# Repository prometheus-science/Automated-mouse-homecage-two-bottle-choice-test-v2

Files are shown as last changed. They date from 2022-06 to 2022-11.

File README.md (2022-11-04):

# Automated-mouse-homecage-two-bottle-choice-test-v2
  
## a fork of the Kravitz lab device hosted on hackaday https://hackaday.io/project/160388  
  
|components:  |links|Digikey|
|--|--|--|
|1 	× 	3D printed housing and cover See files area for STLs  |||
|1 	× 	Adafruit M0 Feather Adalogger| https://www.adafruit.com/product/2796  |https://www.digikey.co.uk/en/products/detail/adafruit-industries-llc/2796/5804105|
|2 	× 	Hydropac valves| https://labproductsinc.com/product/hydropac-alternative-watering-system/  ||
|2 	× 	15mL conical tube | https://www.amazon.com/Plastic-Graduated-Centrifuge-Measuring-Conical/dp/B07BF6GCXP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  ||
|1 	× 	3 cell battery| https://www.adafruit.com/product/353  ||
|1 	× 	Short female headers for Feather |https://www.adafruit.com/product/2940  |https://www.digikey.co.uk/en/products/detail/sullins-connector-solutions/PPPC161LFBN-RC/810188|
|1 	× 	Adafruit Feather OLED wing| https://www.adafruit.com/product/2900  |https://www.digikey.co.uk/en/products/detail/adafruit-industries-llc/2900/5810890|
|2 	× 	JST 11" 3 pin assemblies| https://vetco.net/products/jst-ph-connector-male-female-pair-pre-wired-3-pin  |https://www.digikey.co.uk/en/products/detail/jst-sales-america-inc/ASPHSPH24K305/6009459 and https://www.digikey.co.uk/en/products/detail/jst-sales-america-inc/PHR-3/527357|
|2 	× 	JST 3 pin right angle connector |https://www.digikey.com/products/en?keywords=S3B-PH-K-S(LF)(SN)  |https://www.digikey.co.uk/en/products/detail/jst-sales-america-inc/S3B-PH-K-S-LF-SN/926627|
|2 	× 	SparkFun Photo Interrupter Breakout Board - GP1A57HRJ00F| https://www.sparkfun.com/products/9322  |https://www.digikey.co.uk/en/products/detail/sparkfun-electronics/BOB-09322/6006049|
|2 	× 	Resistor 1K Ohm 1/4th Watt| https://www.sparkfun.com/products/13760  |https://www.digikey.co.uk/en/products/detail/stackpole-electronics-inc/CF14JT1K00/1741314|
|2 	× 	Photo Interrupter - GP1A57HRJ00F| https://www.sparkfun.com/products/9299  |https://www.digikey.co.uk/en/products/detail/sharp-socle-technology/GP1A57HRJ00F/718287|
|2 	× 	(optional) BNC output cables | http://www.l-com.com/coaxial-test-cable-bnc-female-6-leads-with-tinned-end  |https://www.digikey.co.uk/en/products/detail/mueller-electric-co/BU-P4969/4073809|
|1 	× 	microSD card 8g class4  ||https://www.digikey.co.uk/en/products/detail/parallax-inc/32328/8638942|

an easier to print frame: 
https://www.tinkercad.com/things/bckWmv0TgYV

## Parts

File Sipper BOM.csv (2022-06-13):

Qty | Part | Link | Price | Total
1 | Adafruit Feather M0 Adalogger | https://www.adafruit.com/product/2796 | $19.95 | $19.95
1 | Lithium Ion Battery Pack - 3.7V 6600mAh | https://www.adafruit.com/product/353 | $29.50 | $29.50
1 | Adafruit FeatherWing OLED - 128x32 OLED | https://www.adafruit.com/product/2900 | $14.95 | $14.95
1 | Short Headers Kit for Feather - 12-pin + 16-pin Female Headers | https://www.adafruit.com/product/2940 | $1.50 | $1.50
2 | 1k resistor | any brand or supplier will do | $0.20 | $0.40
2 | Photo Interrupter - GP1A57HRJ00F | https://www.sparkfun.com/products/9299 | $2.50 | $5.00
2 | SparkFun Photo Interrupter Breakout Board - GP1A57HRJ00F | https://www.sparkfun.com/products/9322 | $1.50 | $3.00
1 | MicroSD card | https://www.amazon.com/Kingston-microSDHC-Class-Memory-SDC4/dp/B00200K1TS/ | $6.00 | $6.00
2 | JST cable | https://www.sparkfun.com/products/9915 | $1.50 | $3.00
2 | Plastic valves | https://labproductsinc.com/product/hydropac-alternative-watering-system/ | $0.50 | $1.00
2 | 10mL syringes | https://www.amazon.com/dp/B01JJYDFHM | $0.50 | $1.00
Total |  |  |  | $85.30

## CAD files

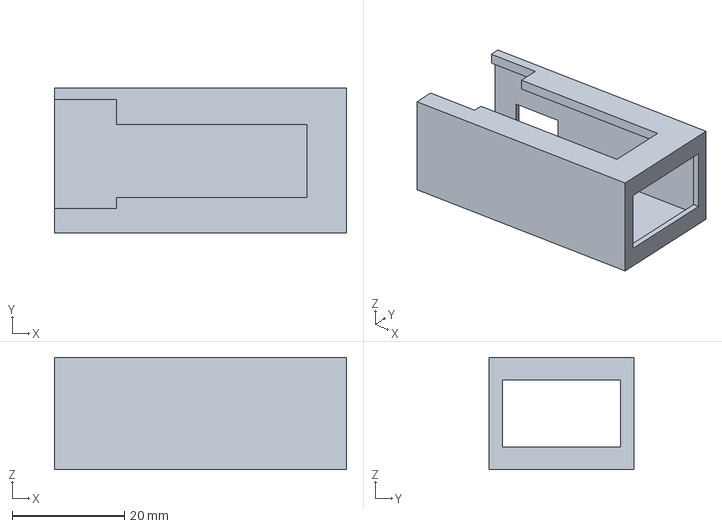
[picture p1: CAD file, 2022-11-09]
3D_models/derivative/freecad_remodel/motor_fit_test.amf
52.0 x 25.9 x 20.0 mm

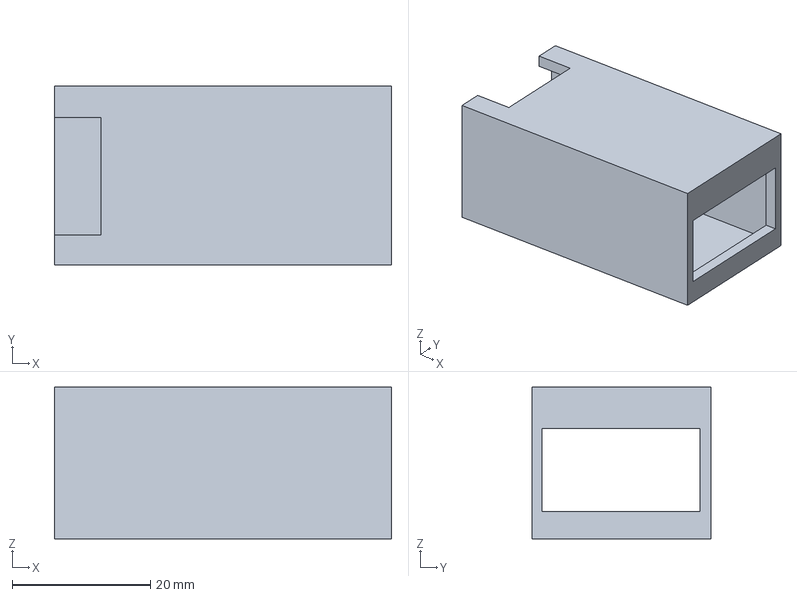
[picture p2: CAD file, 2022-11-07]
3D_models/derivative/test_electronics_fit.amf
48.8 x 25.9 x 22.0 mm

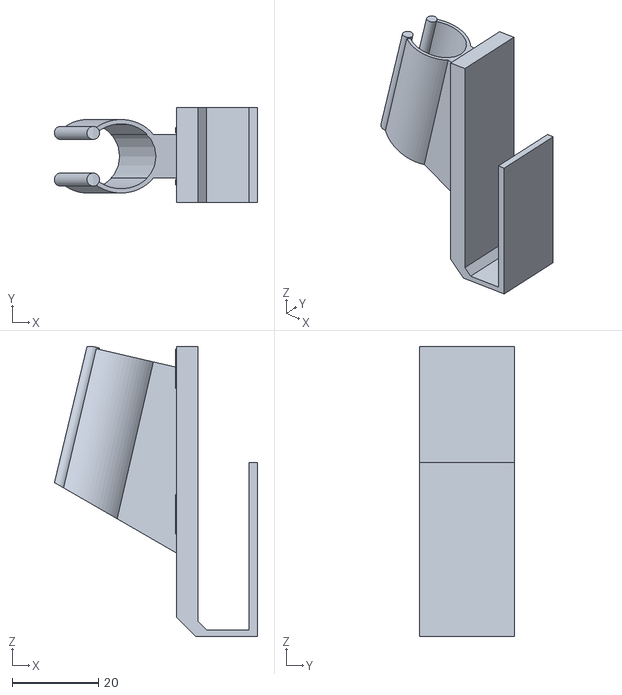
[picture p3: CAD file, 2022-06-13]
3D_models/Mini sipper tube holder.stl
47.0 x 22.0 x 67.1

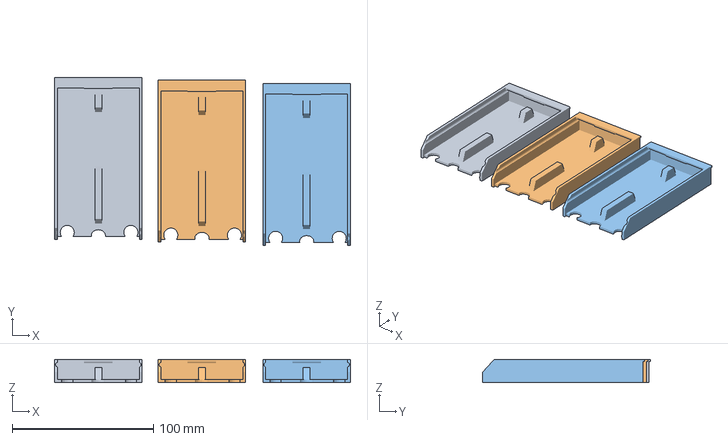
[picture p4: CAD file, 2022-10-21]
3D_models/derivative/electronics_holder_creality.3mf
209.3 x 118.7 x 16.5 mm
sipper_cover.stl x 3

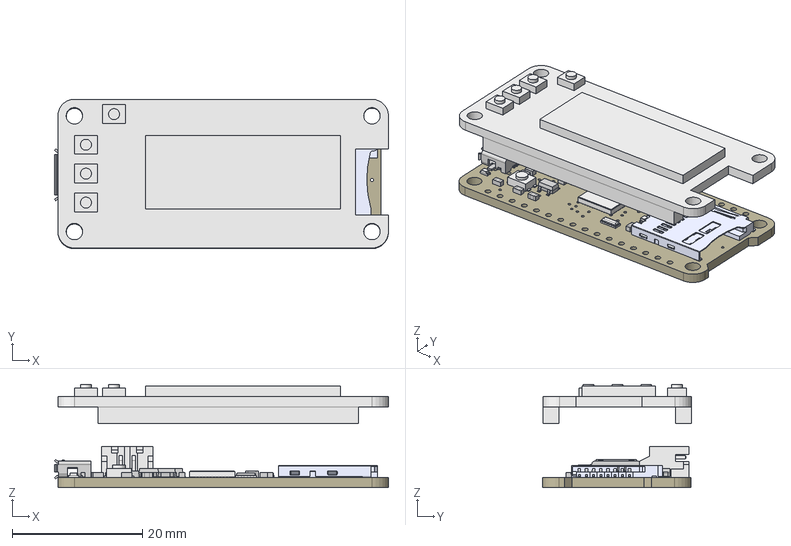
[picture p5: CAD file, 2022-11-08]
3D_models/derivative/freecad_remodel/remodel_freecad.FCStd
51.3 x 23.0 x 15.9 mm
Board
0805-NO
0805-NO001
0805-NO002
0805-NO003
0603-NO
0603-NO001
0603-NO002
0603-NO003
0603-NO004
0603-NO005
0603-NO006
0603-NO007
0603-NO008
0603-NO009
CHIPLED_0805_NOOUTLINE
CHIPLED_0805_NOOUTLINE001
CHIPLED_0805_NOOUTLINE002
TQFN44_7MM
KMR2
RESONATOR-SMD
4UCONN_20329_V2
SOT23-5
SOT23-006
SOD-123
JSTPH2
MICROSD
_0603MP
Feather OLED Wing v11

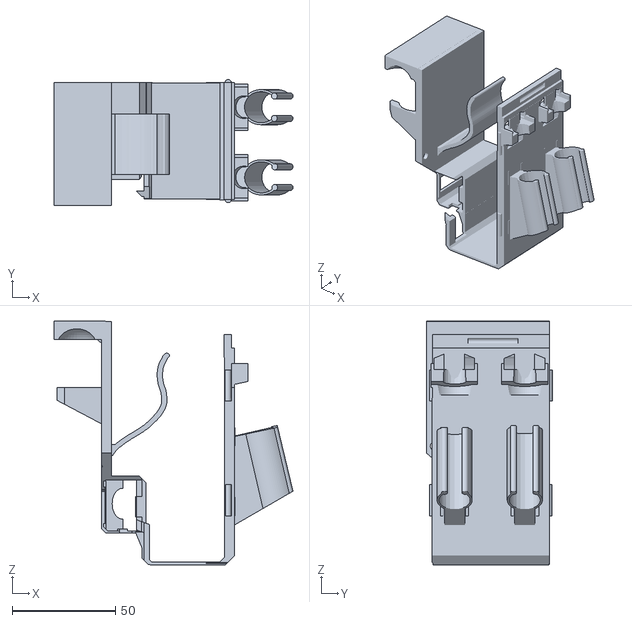
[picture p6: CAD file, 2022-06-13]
3D_models/Sipper base.stl
115.5 x 60.9 x 117.8

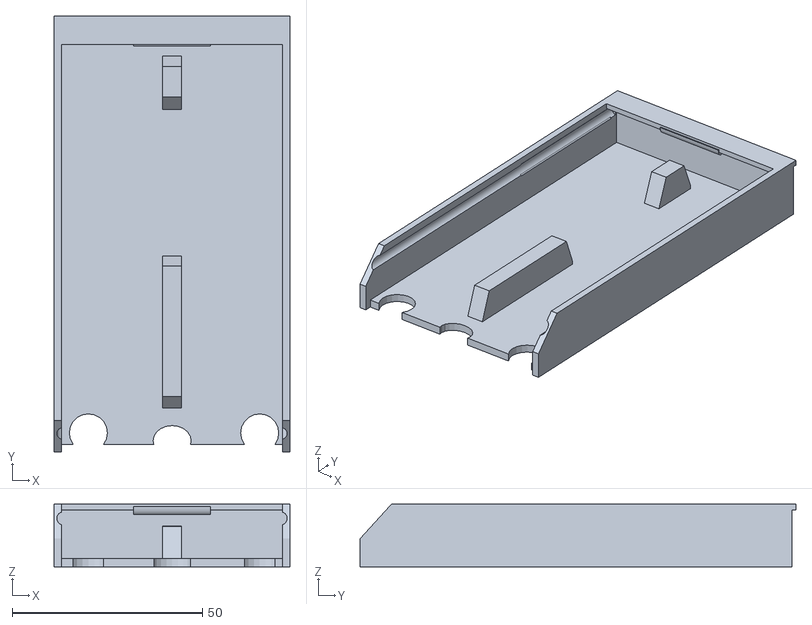
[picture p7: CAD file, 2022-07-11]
3D_models/derivative/sipper_cover.stl
62.0 x 114.5 x 16.5

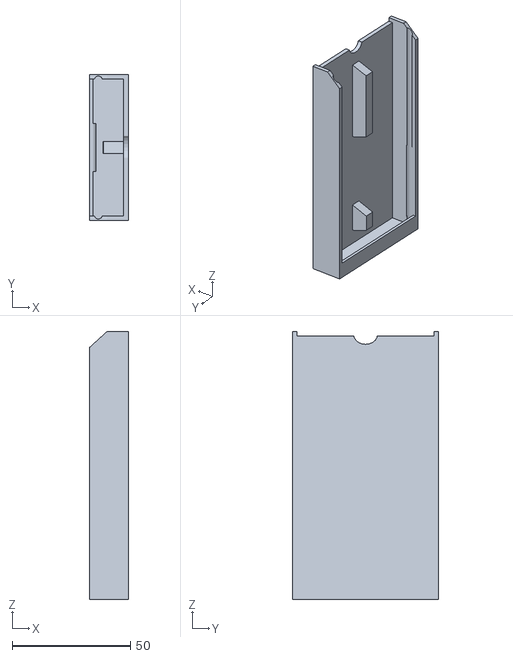
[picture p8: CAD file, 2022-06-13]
3D_models/Sipper cover.stl
16.5 x 62.0 x 113.5

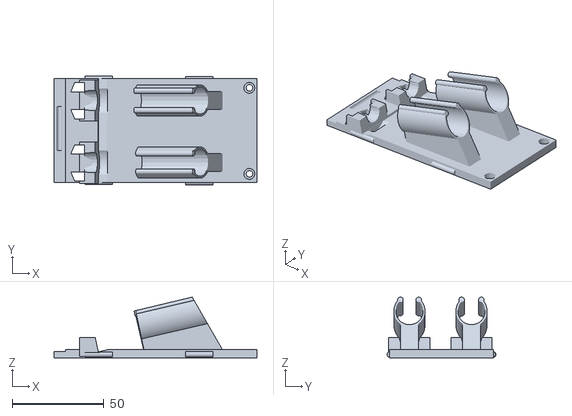
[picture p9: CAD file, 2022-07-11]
3D_models/derivative/tube_holder.stl
110.9 x 59.6 x 33.2

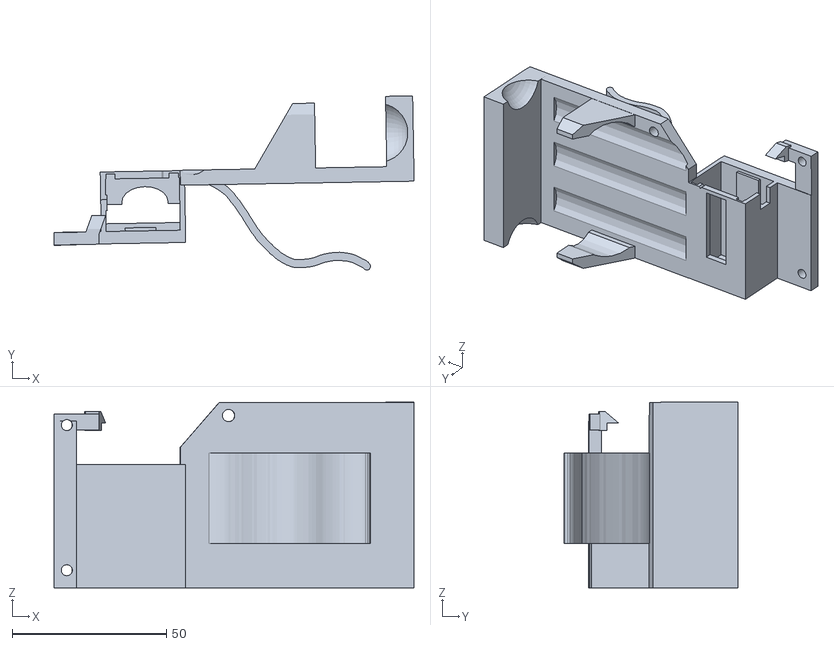
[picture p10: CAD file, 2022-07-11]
3D_models/derivative/electronics_holder.stl
116.6 x 56.5 x 60.2

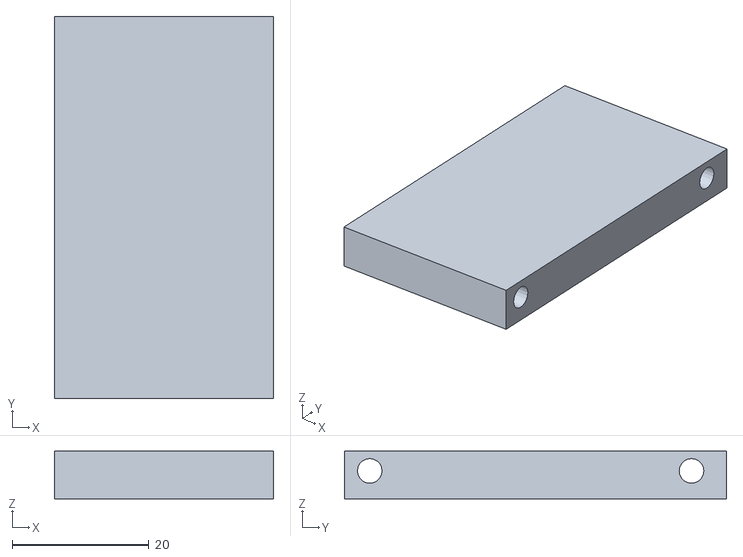
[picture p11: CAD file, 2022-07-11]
3D_models/derivative/link.stl
32.0 x 55.8 x 7.00

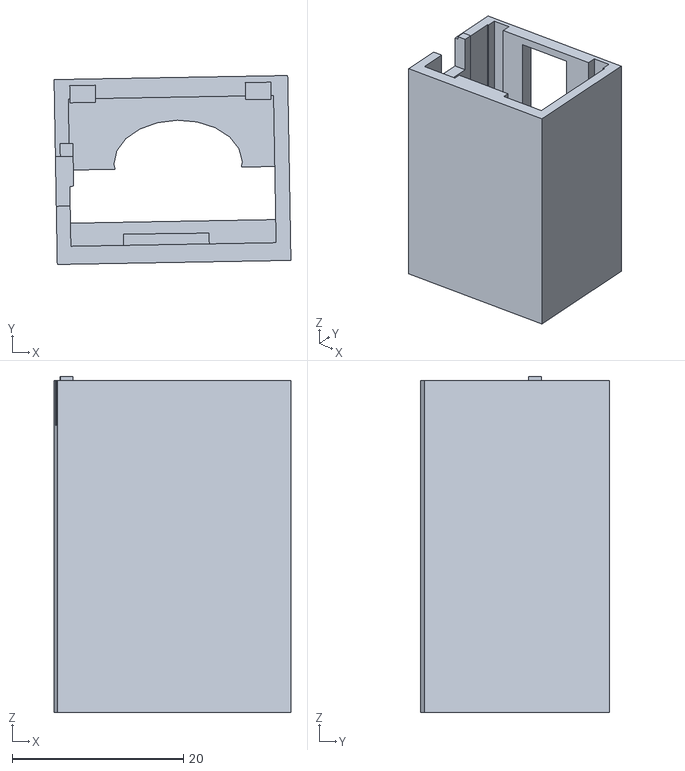
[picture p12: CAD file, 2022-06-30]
3D_models/derivative/holder_test.stl
27.7 x 22.1 x 39.2

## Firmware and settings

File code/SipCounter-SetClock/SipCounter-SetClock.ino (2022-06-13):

/********************************************************
  Clock setting function for Adafruit M0 feather board.  This will set the RTC to the current computer date/time
  and the RTC will maintain that time as long as a battery is connected.  If disconnected just flash this again to
  reset it.

  Written by Lex Kravitz
  National Institute of Diabetes and Digestive and Kidney Disease
  August, 2018

  This project code includes code from:
  *** Adafruit, who made the hardware breakout boards and associated code ***

  Cavemoa's excellent examples of datalogging with the Adalogger:
  https://github.com/cavemoa/Feather-M0-Adalogger

  Uses Arduino Time library http://playground.arduino.cc/code/time
  Maintained by Paul Stoffregen https://github.com/PaulStoffregen/Time

  Uses Arduino Zero RTC library https://www.arduino.cc/en/Reference/RTC
  Maintained by Arturo Guadalupi https://github.com/arduino-libraries/RTCZero

  Uses Pong game code from Matt Watson available here:
  https://www.hackster.io/mwatson/world-s-smallest-pong-a45ea9

  This project is released under The MIT license:

  Copyright (c) 2008 Matias Korhonen

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
  THE SOFTWARE IS PROVIDED "AS IS", WITHOUT WARRANTY OF ANY KIND, EXPRESS OR
  IMPLIED, INCLUDING BUT NOT LIMITED TO THE WARRANTIES OF MERCHANTABILITY,
  FITNESS FOR A PARTICULAR PURPOSE AND NONINFRINGEMENT. IN NO EVENT SHALL THE
  AUTHORS OR COPYRIGHT HOLDERS BE LIABLE FOR ANY CLAIM, DAMAGES OR OTHER
  LIABILITY, WHETHER IN AN ACTION OF CONTRACT, TORT OR OTHERWISE, ARISING FROM,
  OUT OF OR IN CONNECTION WITH THE SOFTWARE OR THE USE OR OTHER DEALINGS IN
  THE SOFTWARE.
********************************************************/


/********************************************************
  Setup code
********************************************************/
#include <Adafruit_SSD1306.h>
#include <Wire.h>
#include <RTCZero.h>
#include <SPI.h>
#include <Adafruit_GFX.h>
#include <TimeLib.h> //include the Arduino Time library
#define OLED_RESET 4
Adafruit_SSD1306 display(OLED_RESET);

// initialize variables (these will be overwritten so doesn't really matter what they are)
byte months = 1;
byte days = 1;
byte years = 1;
byte hours = 1;
byte minutes = 1;
byte seconds = 1;

char s_month[5];
int tmonth, tday, tyear, thour, tminute, tsecond;
static const char month_names[] = "JanFebMarAprMayJunJulAugSepOctNovDec";

RTCZero rtc;

void setup() {
  /********************************************************
       These commands set the time to the current computer time - unfortunately the device needs to be reflashed to update the time
     ********************************************************/
  rtc.begin(); // initialize RTC

  // __DATE__ is a C++ preprocessor string with the current date in it.
  // It will look something like 'Mar  13  2016'.
  // So we need to pull those values out and convert the month string to a number.
  sscanf(__DATE__, "%s %d %d", s_month, &tday, &tyear);

  // Similarly, __TIME__ will look something like '09:34:17' so get those numbers.
  sscanf(__TIME__, "%d:%d:%d", &thour, &tminute, &tsecond);

  // Find the position of this month's string inside month_names, do a little
  // pointer subtraction arithmetic to get the offset, and divide the
  // result by 3 since the month names are 3 chars long.
  tmonth = (strstr(month_names, s_month) - month_names) / 3;

  months = tmonth + 1;  // The RTC library expects months to be 1 - 12.
  days = tday;
  years = tyear - 2000; // The RTC library expects years to be from 2000.
  hours = thour;
  minutes = tminute;
  seconds = tsecond;

  rtc.setTime(hours, minutes, seconds);
  rtc.setDate(days, months, years);


  /********************************************************
       Start, clear, and setup the display
     ********************************************************/
  display.begin(SSD1306_SWITCHCAPVCC, 0x3C);  // initialize with the I2C addr 0x3C (for the 128x32)
  display.ssd1306_command(SSD1306_SETCONTRAST);
  display.ssd1306_command(0); // Where c is a value from 0 to 255 (sets contrast e.g. brightness)

  display.clearDisplay();
  display.display();
  display.setRotation(4);
  display.setTextSize(1);
  display.setTextColor(WHITE);
}

/********************************************************
  Main loop
********************************************************/
void loop() {
  display.setCursor(5, 0);
  display.print ("RTC has been set to:");
  
  display.fillRoundRect (00, 10, 132, 12, 1, BLACK);
  
  
  display.setCursor(5, 12);
  display.print(rtc.getMonth());
  display.print("/");
  display.print(rtc.getDay());
  display.print("/");
  display.print(rtc.getYear() + 2000);
  display.print(" ");
  display.print(rtc.getHours());
  display.print(":");
  if (rtc.getMinutes() < 10)
    display.print('0');      // Trick to add leading zero for formatting
  display.print(rtc.getMinutes());
  display.print(":");
  if (rtc.getSeconds() < 10)
    display.print('0');      // Trick to add leading zero for formatting
  display.print(rtc.getSeconds());

  display.setCursor(5, 25);
  display.print ("Reflash sipper code");
  
  display.display();
  delay (1000);

  
}

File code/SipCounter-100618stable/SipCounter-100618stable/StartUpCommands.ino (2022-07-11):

/********************************************************
  Start Up Commands
********************************************************/
void StartUpCommands () {
  Serial.begin(115200);

  /********************************************************
    These commands are associated with the low power sleep states
  ********************************************************/
  SYSCTRL->VREG.bit.RUNSTDBY = 1;
  SYSCTRL->DFLLCTRL.bit.RUNSTDBY = 1;
  USBDevice.detach();
  for (byte i = 0; i <= 20; i++) {
    pinMode(i, INPUT_PULLUP);
  }

  /********************************************************
     Start RTC
   ********************************************************/
  rtc.begin(); // initialize RTC

  /********************************************************
    Setting digital pin modes
  ********************************************************/
  pinMode(LeftSip, INPUT);
  pinMode(RightSip, INPUT);
  pinMode (RED_LED, OUTPUT);
  pinMode (GREEN_LED, OUTPUT);
  pinMode(buttonA, INPUT_PULLUP);
  pinMode(buttonB, INPUT_PULLUP);
  pinMode(buttonC, INPUT_PULLUP);
  pinMode (outLeft, OUTPUT);
  pinMode (outRight, OUTPUT);

  digitalWrite(GREEN_LED, LOW);
  digitalWrite(RED_LED, LOW);
  digitalWrite(outLeft, LOW);
  digitalWrite(outRight, LOW);

  /********************************************************
    SD Card setup function
  ********************************************************/
  CreateFile();
  writeHeader();

  /********************************************************
    Start, clear, and setup the display
  ********************************************************/
  display.begin(SSD1306_SWITCHCAPVCC, 0x3C);  // initialize with the I2C addr 0x3C (for the 128x32)
  display.ssd1306_command(SSD1306_SETCONTRAST);
  display.ssd1306_command(0); // Where c is a value from 0 to 255 (sets contrast e.g. brightness)

  display.setRotation(4);
  display.setTextSize(1);
  display.setTextColor(WHITE);

  /********************************************************
     Display start date time and filename
    ********************************************************/
  display.clearDisplay();
  DisplayStartScreen();

  //delay until button A is pressed to start sipper
  while (digitalRead(buttonA) == HIGH) {
    if (PongActive == false) {
      display.fillRoundRect (00, 0, 132, 11, 1, BLACK);
      leftmillis = millis();
      rightmillis = millis();
      startmillis = millis();
      DisplayStartScreen();
    }

    //Code for starting the sequence to set the clock and sipper #
    if (digitalRead(buttonB) == LOW) {  //if button B is held
      delay (500);
      if (digitalRead(buttonB) == LOW) {
        SetSequence = 1;
        SetClockVars();
        display.clearDisplay(); //after setting variables, return to start screen
        DisplayStartScreen();
      }
    }

    //Activate Pong game!
    if (PongActive == false & digitalRead(buttonC) == LOW) {
      delay (1000);
      if (PongActive == false & digitalRead(buttonC) == LOW) {
        PongActive = true;
        PongSplash();
      }
    }

    //Code for starting PONG!
    if (PongActive == true) {
      Pong();
    }

  }
  Blink (RED_LED, 50, 3);
}

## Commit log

2022-06-23 update printable files
    [Mini sipper tube holder.stl, Sipper base.stl, Sipper cover.stl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]
2022-06-23 refine designs
    [electronics_holder.stl, sippers_cover.stl]
2022-06-26 update print files
    [sipper_cover.stl, sippers_cover.stl, tube_holder.stl]
2022-06-30 update designs
    [electronics_holder.3mf, electronics_holder.stl, holder_test.stl]
2022-07-11 add arduino code and clean up 3D models
    [electronics_holder.3mf, electronics_holder.stl, electronics_holder_creality.3mf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]
2022-11-04 start porting model to freecad
    [remodel_freecad.FCStd, test_electronics_fit.amf]
2022-11-07 more work on new case
    [remodel_freecad.FCStd]
2022-11-07 update fitting
    [remodel_freecad.FCStd, test_electronics_fit.amf]
2022-11-08 work on electronics casing
    [motor_fit_test.amf, remodel_freecad.FCStd]
